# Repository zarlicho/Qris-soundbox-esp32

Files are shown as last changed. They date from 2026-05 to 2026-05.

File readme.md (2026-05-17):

# QRIS Soundbox System - Complete Documentation

## Project Overview

QRIS Soundbox adalah sistem notifikasi pembayaran realtime yang dikembangkan untuk menerima dan memproses notifikasi pembayaran QRIS melalui protokol MQTT. Sistem ini mengintegrasikan payment gateway Midtrans dengan device soundbox melalui Adafruit server yang berfungsi sebagai webhook endpoint dan MQTT broker.

## PCB design
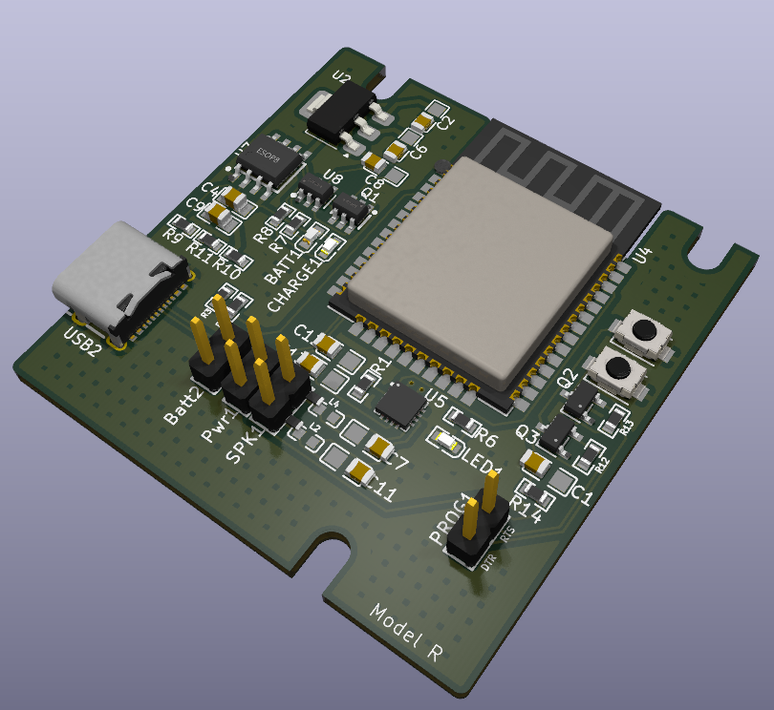
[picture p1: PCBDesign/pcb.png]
PCB


## System Architecture

### Core Components

1. **Payment Gateway**: Midtrans sebagai processor pembayaran QRIS
2. **Server Infrastructure**: Adafruit server dengan webhook endpoint dan MQTT broker
3. **QRIS Soundbox Device**: Device subscriber yang memberikan feedback audio dan visual
4. **Monitoring Dashboard**: Adafruit IO untuk monitoring dan logging

### Technology Stack

- **Payment Processing**: Midtrans Payment Gateway
- **Communication Protocol**: MQTT (Message Queuing Telemetry Transport)
- **Server Platform**: Adafruit IO
- **Device Communication**: MQTT Subscribe/Publish pattern
- **Data Format**: JSON for payment callback data

## System Flow Documentation

### 1. Payment Initiation Flow

**Customer Journey:**
- Customer melakukan scan QR code menggunakan mobile banking atau e-wallet
- Aplikasi mobile memproses pembayaran melalui sistem perbankan
- Data pembayaran diteruskan ke Midtrans payment gateway untuk processing

### 2. Payment Processing Flow

**Midtrans Processing:**
- Midtrans memvalidasi dan memproses transaksi pembayaran
- System menentukan status pembayaran (Success/Failed)
- Callback notification digenerate berdasarkan hasil processing

### 3. Webhook Callback Flow

**Server Side Processing:**
- Midtrans mengirim HTTP POST callback ke webhook endpoint Adafruit server
- Server menerima dan memvalidasi data callback
- Data callback diparse dan diverifikasi integritasnya
- Jika valid, data diproses untuk publikasi ke MQTT broker

**Data Validation Steps:**
- Signature verification untuk keamanan
- Transaction ID validation
- Amount dan merchant validation
- Timestamp verification

### 4. MQTT Publication Flow

**Message Broadcasting:**
- Validated payment data dipublikasi ke MQTT broker (Adafruit IO)
- Data dikirim ke specific topic: `qris/payment/notification`
- Message format menggunakan JSON structure
- QoS (Quality of Service) level ditentukan untuk reliability

**Sample MQTT Payload:**
```json
{
    "additionalInfo": {
        "issuerID": "93600821",
        "nettAmount": "9990.00",
        "payerName": "TEST",
        "payerPhoneNumber": "9360082112345678919",
        "paymentReferenceNo": "J0CP1INR2LOO",
        "posID": "A01",
        "retrievalReferenceNo": "1cqn60h00775",
        "totalRefund": "0.00"
    },
    "amount": {
        "currency": "IDR",
        "value": "10000.00"
    },
    "latestTransactionStatus": "00",
    "originalPartnerReferenceNo": "23545346"
}
```

### 5. Device Subscription Flow

**QRIS Soundbox Processing:**
- Device maintain persistent connection ke MQTT broker
- Subscribe ke topic `qris/payment/notification`
- Receive realtime notification ketika ada payment baru
- Parse JSON payload untuk extract payment information

### 6. User Feedback Flow

**Audio & Visual Feedback:**
- **Success Payment**: Play success sound + display transaction details
- **Failed Payment**: Play error sound + display failure message
- **Display Information**: Amount, transaction time, status, transaction ID
- **Logging**: Record transaction untuk audit trail

### 7. Monitoring & Analytics Flow

**Dashboard Integration:**
- Adafruit IO dashboard menampilkan realtime payment statistics
- Mobile app atau web interface untuk remote monitoring
- Transaction history dan analytics
- Device status monitoring (online/offline)

## Technical Implementation Details

### MQTT Configuration

**Broker Settings:**
- **Host**: io.adafruit.com
- **Port**: 1883 (non-SSL) atau 8883 (SSL)
- **Username**: Adafruit IO username
- **Key**: Adafruit IO key
- **Keep Alive**: 60 seconds
- **Clean Session**: True

### Webhook Endpoint Configuration

**Midtrans Webhook Setup:**
- **URL**: `https://io.adafruit.com/api/v2/webhooks/[webhook-key]`
- **Method**: POST
- **Content-Type**: application/json
- **Timeout**: 30 seconds
- **Retry**: 3 attempts dengan exponential backoff

### Error Handling Strategy

**Connection Resilience:**
- Auto-reconnect untuk MQTT connection
- Offline message queuing
- Retry mechanism untuk failed callbacks
- Graceful degradation ketika server unavailable

**Data Integrity:**
- Duplicate transaction detection
- Checksum verification
- Transaction sequence validation
- Timeout handling untuk stuck transactions

### Security Considerations

**Data Protection:**
- HTTPS untuk webhook communications
- MQTT over SSL/TLS
- Signature validation dari Midtrans
- API key rotation policy
- Access control untuk MQTT topics

**Privacy Compliance:**
- Customer data anonymization
- PCI DSS compliance untuk payment data
- Log data retention policy
- Secure storage untuk transaction records

## Deployment Architecture

### Production Environment

**Infrastructure Requirements:**
- Reliable internet connection untuk device
- Backup power supply untuk continuous operation
- Local storage untuk offline transaction queuing
- Audio output system untuk sound notifications

**Scalability Considerations:**
- Multiple device support dengan unique client IDs
- Load balancing untuk high-volume transactions
- Database optimization untuk transaction storage
- Caching strategy untuk frequent queries

---

## System Flow Diagram

```mermaid
flowchart TD
    A[Customer] --> B[Scan QR Code]
    B --> C[Mobile Banking/E-Wallet App]
    C --> D[Payment Processing]
    D --> E[Midtrans Payment Gateway]
    
    E --> F{Payment Status}
    F -->|Success| G[Payment Callback]
    F -->|Failed| H[Failed Callback]
    
    G --> I[Webhook Endpoint<br/>Adafruit Server]
    H --> I
    
    I --> J[Process Callback Data]
    J --> K[Validate Payment Data]
    K --> L{Data Valid?}
    
    L -->|Yes| M[Publish to MQTT Broker<br/>Adafruit IO]
    L -->|No| N[Log Error & Reject]
    
    M --> O[MQTT Topic<br/>qris/payment/notification]
    
    O --> P[QRIS Soundbox Device<br/>MQTT Subscriber]
    P --> Q[Receive Payment Data]
    Q --> R[Parse JSON Data]
    R --> S[Extract Payment Info<br/>Amount, Status, Transaction ID]
    
    S --> T{Payment Success?}
    T -->|Yes| U[Play Success Sound]
    T -->|Failed| V[Play Failed Sound]
    
    U --> W[Display Transaction Info<br/>Amount, Time, Status]
    V --> W
    
    W --> X[Log Transaction]
    X --> Y[Ready for Next Payment]
    
    %% Additional Components
    Z[Adafruit IO Dashboard] --> O
    AA[Mobile App/Web Monitor] --> Z
    
    %% Styling
    classDef customer fill:#e1f5fe
    classDef payment fill:#f3e5f5
    classDef server fill:#e8f5e8
    classDef device fill:#fff3e0
    classDef data fill:#fce4ec
    
    class A,B,C customer
    class D,E,F,G,H payment
    class I,J,K,L,M,O,Z server
    class P,Q,R,S,T,U,V,W,X,Y device
    class AA data
```

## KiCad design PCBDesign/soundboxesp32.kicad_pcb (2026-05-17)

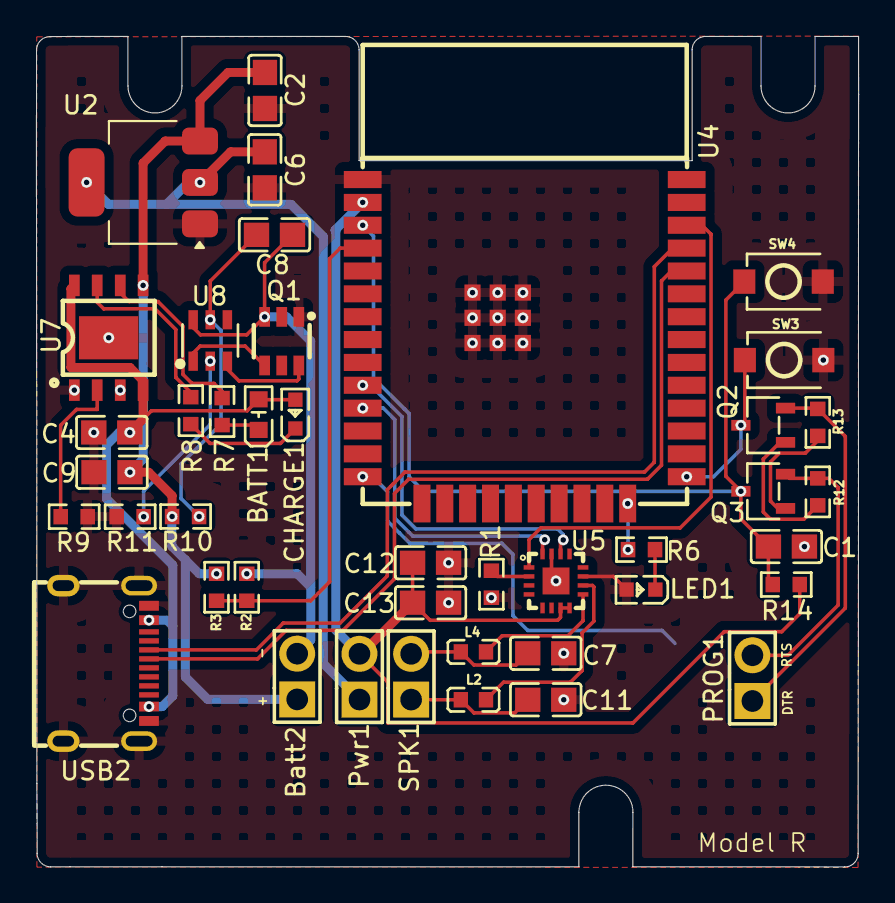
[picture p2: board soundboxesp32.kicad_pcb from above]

Board: 2 copper layers, 45.7 x 46.1 mm, 43 parts (1 on the bottom side), 35 nets.

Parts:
BATT1: A-SP192DGHC-C01-4T; LED0603-FD
Batt2: ZX-PZ2.54-1-2PZZ; HDR-TH_2P-P2.54-V-M
C1, C4, C8, C12: 100nF; C0805
C2, C6: 22uF; C0805
C7, C11: 220pF; C0805
C9, C13: 10uF; C0805
CHARGE1: XL-1608SURC-06; LED0603-RD_RED
L2, L4: 330Ω; L0603
LED1: XL-1608SURC-06; LED0603-RD_RED
PROG1: ZX-PZ2.54-1-2PZZ; HDR-TH_2P-P2.54-V-M
Pwr1: ZX-PZ2.54-1-2PZZ; HDR-TH_2P-P2.54-V-M
Q1: FS8205; SOT-23-6_L2.9-W1.6-P0.95-LS2.8-BR
Q2, Q3: MMBT3904LT1G; SOT-23-3_L2.9-W1.6-P1.90-LS2.8-BR
R1, R3: RC0603FR-07100KL; R0603
R2: FRC0603F3003TS; R0603
R6, R7, R8, R9, R11: 1K; R0603
R10: 100Ω; R0603
R12, R13, R14: 10K; R0603
SPK1: ZX-PZ2.54-1-2PZZ; HDR-TH_2P-P2.54-V-M
SW1, SW3, SW4: TS-1088-AR02016; SW-SMD_L3.9-W3.0-P4.45
U2: AMS1117-3.3; SOT-223-3_TabPin2
U4: ESP32-WROOM-32E(4MB); WIFI-SMD_ESP32-WROOM-32E
U5: MAX98357AETE+T; TQFN-16_L3.0-W3.0-P0.50-BL-EP1.5
U7: TP4056; ESOP-8_L4.9-W3.9-P1.27-LS6.0-BL-EP
U8: DW01A_C2927799; SOT-23-6_L2.9-W1.6-P0.95-LS2.8-BL
USB2: TYPE-C 16PIN 2MD(073); USB-C-SMD_TYPE-C-6PIN-2MD-073

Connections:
+3.3V: C12.1, C13.1, Pwr1.2, R14.2, U4.2 (3V3), U5.7 (VDD), U5.8 (VDD)
+5V: BATT1.1 (A), C4.1, CHARGE1.2 (A), U7.4 (VCC), U7.8 (CE), USB2.2 (VBUS), USB2.11 (VBUS)
+BATT: Batt2.1, C2.2, C9.1, R3.2, R10.2, U2.3 (VI), U7.5 (BAT)
BCLK: U4.11 (IO26), U5.16 (BCLK)
DIN: U4.36 (IO22), U5.1 (DIN)
DTR: PROG1.1, Q2.2, R13.1
GND: C1.2, C2.1, C4.2, C6.1, C7.1, C9.2, C11.1, C12.2, C13.2, LED1.2 (A), Q1.1 (S1), R1.1, R9.2, R11.1, SW1.2, SW3.2, SW4.2, U2.1 (GND), U4.1 (GND), U4.39 (GND), U5.11 (GND), U5.15 (GND), U5.17 (EP), U7.1 (TEMP), U7.3 (GND), U7.9 (EP), USB2.1 (GND), USB2.12 (GND), USB2.13 (SHELL), USB2.14 (SHELL)
GPIO0: Q2.3, SW3.1, U4.25 (IO0)
IO12: SW1.1, U4.14 (IO12)
LRC: U4.10 (IO25), U5.14 (LRCLK)
unnamed: BATT1.2 (K), R7.2
unnamed: C7.2, L4.2, SPK1.2
unnamed: C11.2, L2.2, SPK1.1
unnamed: CHARGE1.1 (K), R8.2
unnamed: LED1.1 (K), R6.2
unnamed: Q1.6 (G1), U8.3 (OC)
unnamed: Q1.4 (G2), U8.1 (OD)
unnamed: Batt2.2, C8.2, Q1.3 (S2), R2.1, U8.6 (VSS)
unnamed: Q2.1, R12.2
unnamed: Q3.1, R13.2
unnamed: C6.2, Pwr1.1, U2.2 (VO)
unnamed: R6.1, U4.24 (IO2)
unnamed: R1.2, U5.2 (GAIN_SLOT)
unnamed: L2.1, U5.10 (OUTN)
unnamed: L4.1, U5.9 (OUTP)
unnamed: R9.1, U7.2 (PROG)
unnamed: R8.1, U7.7 (~CHRG)
unnamed: R7.1, U7.6 (~STDBY)
unnamed: R11.2, U8.2 (CSI)
unnamed: C8.1, R10.1, U8.5 (VDD)
RESET: C1.1, Q3.3, R14.1, SW4.1, U4.3 (EN)
RTS: PROG1.2, Q3.2, R12.1
RX: U4.34 (RXD0), USB2.6 (DP1), USB2.8 (DP2)
SENSOR_VP: R2.2, R3.1, U4.4 (SENSOR_VP)
TX: U4.35 (TXD0), USB2.5 (DN2), USB2.7 (DN1)

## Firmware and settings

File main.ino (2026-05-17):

#include "Adafruit_MQTT_Client.h"
#include <HTTPClient.h>
#include <WiFiClientSecure.h>
#include <WiFi.h>
#include <WiFiManager.h>
#include "Adafruit_MQTT.h"
#include "ArduinoJson.h"
#include "Arduino.h"
#include <Arduino.h>
#include <LittleFS.h>
#include "driver/i2s.h"

// dac connection
#define I2S_DOUT  22
#define I2S_BCLK  26
#define I2S_LRC   25

// ============Adafruit MQTT CONFIG============
#define AIO_SERVER "io.adafruit.com"
#define AIO_SERVERPORT 1883
#define AIO_USERNAME "your adafruit_username"
#define AIO_KEY "your adafruit_key"
#define FeedName "your feed_name" // kalau pakai adafruit mqtt, biasanya formatnya username/feeds/feedname

// ---------- WAV parsing ----------
struct WavFmt {
  uint16_t audioFormat;   // 1 = PCM
  uint16_t numChannels;   // 1 = mono, 2 = stereo
  uint32_t sampleRate;    // e.g. 16000
  uint16_t bitsPerSample; // 16
  uint32_t dataOffset;    // posisi awal data PCM
  uint32_t dataSize;      // ukuran data PCM (byte)
};

// PIN CONFIG
int button = 12;
int button2 = 13;
float volume = 5.0f;
long buttonTimer = 0;
long longPressTime = 5000;
bool volActive = false;
boolean buttonActive = false;
boolean longPressActive = false;

// MQTT CONTROL
unsigned long lastMQTTCheck = 0;
unsigned long lastMQTTConnectAttempt = 0;
const unsigned long mqttInterval = 100;
const unsigned long mqttReconnectInterval = 30000; // 30 sec
bool mqttConnected = false;

// ---- WiFi reconnect control ----
unsigned long lastWiFiReconnectAttempt = 0;
const unsigned long wifiReconnectInterval = 10000; // 10s
bool portalRequested = false;

bool hasSavedWiFi() {
  // Deteksi kredensial tersimpan di NVS
  // WiFi.SSID() biasanya berisi SSID terakhir yang tersimpan
  return WiFi.psk().length() > 0;
}

void tryWiFiReconnect() {
  if (WiFi.status() != WL_CONNECTED) {
    Serial.println("[WiFi] Lost. Reconnecting...");
    // panggil reconnect cepat
    WiFi.reconnect();
  }
}

// OBJECTS
WiFiClient client;
WiFiClientSecure clientSecure;
HTTPClient http;
WiFiManager wifiManager;

// mqtt config for adafruit only
Adafruit_MQTT_Client mqtt(&client, AIO_SERVER, AIO_SERVERPORT, AIO_USERNAME, AIO_KEY);
Adafruit_MQTT_Subscribe sndBox = Adafruit_MQTT_Subscribe(&mqtt, AIO_USERNAME "/feeds/" FeedName);

StaticJsonDocument<1264> doc;

// AIRTABLE CONFIG
const char* airtableToken = "your_airtable_token";  // Personal Access Token
const char* baseId = "your_airtable_base_id";       // Base ID
const char* tableName = "your_airtable_table_name";
String airtableURL = "https://api.airtable.com/v0/" + String(baseId) + "/" + tableName;

// Custom CSS for dark mode and styling
const char* customCSS = R"rawliteral(
<style>
  :root {
    --bg-primary: #1a1a1a;
    --bg-secondary: #2d2d2d;
    --text-primary: #ffffff;
    --text-secondary: #b0b0b0;
    --accent-color: #00d4aa;
    --accent-hover: #00b894;
    --border-color: #404040;
    --input-bg: #333333;
    --danger-color: #ff6b6b;
  }
  
  * {
    box-sizing: border-box;
    margin: 0;
    padding: 0;
  }
  
  body {
    font-family: 'Segoe UI', Tahoma, Geneva, Verdana, sans-serif;
    background: linear-gradient(135deg, var(--bg-primary) 0%, var(--bg-secondary) 100%);
    color: var(--text-primary);
    min-height: 100vh;
    padding: 20px;
    line-height: 1.6;
  }
  
  .container {
    max-width: 500px;
    margin: 0 auto;
    background: var(--bg-secondary);
    border-radius: 15px;
    box-shadow: 0 10px 30px rgba(0, 0, 0, 0.5);
    overflow: hidden;
  }
  
  .header {
    background: linear-gradient(135deg, var(--accent-color), var(--accent-hover));
    padding: 30px 20px;
    text-align: center;
    color: white;
  }
  
  .header h1 {
    font-size: 2.2em;
    margin-bottom: 10px;
    font-weight: 300;
  }
  
  .header p {
    opacity: 0.9;
    font-size: 1.1em;
  }
  
  .content {
    padding: 30px;
  }
  
  h2, h3 {
    color: var(--accent-color);
    margin-bottom: 20px;
    font-weight: 400;
  }
  
  .btn {
    display: inline-block;
    background: var(--accent-color);
    color: white;
    padding: 12px 30px;
    text-decoration: none;
    border-radius: 25px;
    border: none;
    cursor: pointer;
    font-size: 1em;
    transition: all 0.3s ease;
    margin: 10px 5px;
    min-width: 120px;
  }
  
  .btn:hover {
    background: var(--accent-hover);
    transform: translateY(-2px);
    box-shadow: 0 5px 15px rgba(0, 212, 170, 0.3);
  }
  
  .btn-secondary {
    background: transparent;
    border: 2px solid var(--accent-color);
    color: var(--accent-color);
  }
  
  .btn-secondary:hover {
    background: var(--accent-color);
    color: white;
  }
  
  input[type="text"], input[type="password"], select {
    width: 100%;
    padding: 15px;
    background: var(--input-bg);
    border: 2px solid var(--border-color);
    border-radius: 8px;
    color: var(--text-primary);
    font-size: 1em;
    margin: 10px 0;
    transition: border-color 0.3s ease;
  }
  
  input[type="text"]:focus, input[type="password"]:focus, select:focus {
    outline: none;
    border-color: var(--accent-color);
    box-shadow: 0 0 10px rgba(0, 212, 170, 0.2);
  }
  
  .status-indicator {
    display: inline-block;
    width: 12px;
    height: 12px;
    border-radius: 50%;
    margin-right: 10px;
    background: var(--danger-color);
    animation: pulse 2s infinite;
  }
  
  .status-indicator.connected {
    background: var(--accent-color);
  }
  
  @keyframes pulse {
    0% { opacity: 1; }
    50% { opacity: 0.5; }
    100% { opacity: 1; }
  }
  
  .info-card {
    background: var(--bg-primary);
    padding: 20px;
    border-radius: 10px;
    margin: 20px 0;
    border-left: 4px solid var(--accent-color);
  }
  
  .network-list {
    max-height: 300px;
    overflow-y: auto;
  }
  
  .network-item {
    padding: 15px;
    border-bottom: 1px solid var(--border-color);
    cursor: pointer;
    transition: background 0.3s ease;
  }
  
  .network-item:hover {
    background: var(--bg-primary);
  }
  
  .signal-strength {
    float: right;
    color: var(--text-secondary);
  }
  
  .footer {
    text-align: center;
    padding: 20px;
    color: var(--text-secondary);
    border-top: 1px solid var(--border-color);
  }
  
  @media (max-width: 600px) {
    body { padding: 10px; }
    .container { margin: 0; }
    .header h1 { font-size: 1.8em; }
    .content { padding: 20px; }
  }
</style>
)rawliteral";

// Landing page HTML
const char* landingPageHTML = R"rawliteral(
<!DOCTYPE html>
<html>
<head>
  <meta charset="UTF-8">
  <meta name="viewport" content="width=device-width, initial-scale=1.0">
  <title>Config</title>
</head>
<body>
  <div class="container">
    <div class="header">
      <h1>Soundbox Settings</h1>
    </div>
    
    <div class="content">
      <div class="info-card">
        <h3><span class="status-indicator"></span>Device Status</h3>
        <p><strong>Device ID:</strong> BYR-AJA001</p>
        <p><strong>Status:</strong> Ready for Configuration</p>
      </div>
      
      <div style="text-align: center; margin: 30px 0;">
        <p style="color: var(--text-secondary); margin-bottom: 30px;">
          Settings Wifi untuk device Qris soundbox
        </p>
        
        <a href="/wifi" class="btn">🔧 Konfigurasi WiFi</a>
        
      </div>
      
      <div class="info-card">
        <h3>Langkah-langkah</h3>
        <ol style="color: var(--text-secondary); padding-left: 20px;">
          <li>Klik "Konfigurasi WiFi"</li>
          <li>Pilih Wifi yang tersedia di list</li>
          <li>Masukan password</li>
          <li>Klik save dan tunggu hingga terhubung</li>
        </ol>
      </div>
    </div>
    
    <div class="footer">
      <p>Qris Soundbox BayarAja</p>
    </div>
  </div>
</body>
</html>
)rawliteral";

bool parseWavHeader(File &f, WavFmt &fmt) {
  f.seek(0);
  uint8_t hdr[12];
  if (f.read(hdr, 12) != 12) return false;
  if (memcmp(hdr, "RIFF", 4) != 0 || memcmp(hdr + 8, "WAVE", 4) != 0) return false;

  bool gotFmt = false, gotData = false;
  uint32_t pos = 12;
  while (pos + 8 <= f.size()) {
    f.seek(pos);
    char chunkId[5] = {0};
    f.read((uint8_t*)chunkId, 4);
    uint32_t chunkSize;
    f.read((uint8_t*)&chunkSize, 4);

    pos += 8;
    if (!memcmp(chunkId, "fmt ", 4)) {
      if (chunkSize < 16) return false;
      uint16_t audioFormat, numChannels, bitsPerSample, blockAlign;
      uint32_t sampleRate, byteRate;
      f.read((uint8_t*)&audioFormat, 2);
      f.read((uint8_t*)&numChannels, 2);
      f.read((uint8_t*)&sampleRate, 4);
      f.read((uint8_t*)&byteRate, 4);
      f.read((uint8_t*)&blockAlign, 2);
      f.read((uint8_t*)&bitsPerSample, 2);
      // skip extra fmt bytes if any
      if (chunkSize > 16) f.seek(pos + chunkSize);

      fmt.audioFormat   = audioFormat;
      fmt.numChannels   = numChannels;
      fmt.sampleRate    = sampleRate;
      fmt.bitsPerSample = bitsPerSample;
      gotFmt = true;
      pos += chunkSize;
    } else if (!memcmp(chunkId, "data", 4)) {
      fmt.dataOffset = pos;
      fmt.dataSize   = chunkSize;
      gotData = true;
      break; // data chunk terakhir yang kita butuhkan
    } else {
      // lewati chunk lain (LIST, fact, dsb.)
      pos += chunkSize;
    }
    // align ke genap
    if (chunkSize & 1) pos++;
  }
  return gotFmt && gotData && fmt.audioFormat == 1 && fmt.bitsPerSample == 16;
}

// ---------- Volume ----------
inline void apply_volume(uint8_t* buffer, size_t bytesRead, float vol) {
  int16_t* s = (int16_t*)buffer;
  size_t n = bytesRead / 2;
  for (size_t i = 0; i < n; i++) {
    int32_t v = (int32_t)(s[i] * vol);
    if (v > 32767) v = 32767;
    if (v < -32768) v = -32768;
    s[i] = (int16_t)v;
  }
}

// edited i2s_init
void i2s_init(uint32_t sample_rate, int channels) {
  i2s_config_t i2s_config = {
    .mode = (i2s_mode_t)(I2S_MODE_MASTER | I2S_MODE_TX),
    .sample_rate = (int)sample_rate,                    // pakai dari WAV
    .bits_per_sample = I2S_BITS_PER_SAMPLE_16BIT,
    .channel_format = channels == 2
        ? I2S_CHANNEL_FMT_RIGHT_LEFT
        : I2S_CHANNEL_FMT_ONLY_RIGHT,                   // atau ONLY_LEFT
    .communication_format = I2S_COMM_FORMAT_STAND_I2S,  // cukup STAND_I2S
    .intr_alloc_flags = ESP_INTR_FLAG_LEVEL1,
    .dma_buf_count = 8,
    .dma_buf_len   = 256,                               // dulu 64
    .use_apll = true,                                   // clock lebih stabil
    .tx_desc_auto_clear = true,
    .fixed_mclk = 0
  };
  // i2s_pin_config_t pin_config = { I2S_BCLK, I2S_LRC, I2S_DOUT, I2S_PIN_NO_CHANGE };
  i2s_pin_config_t pin_config = {
    .bck_io_num = I2S_BCLK,
    .ws_io_num  = I2S_LRC,
    .data_out_num = I2S_DOUT,
    .data_in_num  = I2S_PIN_NO_CHANGE
  };


  i2s_driver_install(I2S_NUM_0, &i2s_config, 0, NULL);
  i2s_set_pin(I2S_NUM_0, &pin_config);
  i2s_set_clk(I2S_NUM_0, sample_rate, I2S_BITS_PER_SAMPLE_16BIT,
              (channels == 2) ? I2S_CHANNEL_STEREO : I2S_CHANNEL_MONO);
}

void setupCustomWiFiManager() {
  // Set custom menu items including home/landing page
  std::vector<const char *> menu = {"wifi", "info", "sep", "restart", "exit"};
  wifiManager.setMenu(menu);

  // Set custom CSS for dark mode
  wifiManager.setCustomHeadElement(customCSS);

  // Add custom landing page as root
  wifiManager.setWebServerCallback([&]() {
    wifiManager.server->on("/", [&]() {
      wifiManager.server->send(200, "text/html", String(customCSS) + landingPageHTML);
    });
    
    // Custom info page
    wifiManager.server->on("/info", [&]() {
      String infoHTML = String(customCSS) + R"rawliteral(
        <!DOCTYPE html>
        <html>
        <head>
          <meta charset="UTF-8">
          <meta name="viewport" content="width=device-width, initial-scale=1.0">
          <title>Device Information</title>
        </head>
        <body>
          <div class="container">
            <div class="header">
              <h1>📊 Device Information</h1>
              <p>System Status and Details</p>
            </div>
            
            <div class="content">
              <div class="info-card">
                <h3>💾 System Information</h3>
                <p><strong>Device ID:</strong> BYR-AJA001</p>
                <p><strong>Merchant ID:</strong> )rawliteral" + subMerchantId + R"rawliteral(</p>
                <p><strong>Volume Level:</strong> )rawliteral" + String(volume) + R"rawliteral(/30</p>
              </div>
              
              <div style="text-align: center; margin: 30px 0;">
                <a href="/" class="btn">🏠 Home</a>
                <a href="/wifi" class="btn">🔧 WiFi Config</a>
              </div>
            </div>
            
            <div class="footer">
              <p>Qris Soundbox BayarAja | Real-time Data</p>
            </div>
          </div>
        </body>
        </html>
      )rawliteral";
      
      wifiManager.server->send(200, "text/html", infoHTML);
    });
  });

  // Configure WiFiManager settings
  wifiManager.setConfigPortalTimeout(300); // 5 minutes timeout
  wifiManager.setConnectTimeout(20);       // 20 seconds to connect
  wifiManager.setAPCallback([](WiFiManager *myWiFiManager) {
    Serial.println("Config portal started");
    Serial.print("Connect to: ");
    Serial.println(myWiFiManager->getConfigPortalSSID());
    Serial.print("Go to: http://");
    Serial.println(WiFi.softAPIP());
  });

  // Set custom AP name and password (optional)
  wifiManager.setAPStaticIPConfig(IPAddress(192, 168, 1, 1), 
                         IPAddress(192, 168, 1, 1), 
                         IPAddress(255, 255, 255, 0));
}

// ================= SETUP =================
void setup() {
  Serial.begin(115200);

  pinMode(button, INPUT_PULLUP);
  pinMode(button2, INPUT_PULLUP);

  if (!LittleFS.begin()) {
    Serial.println("LittleFS mount failed");
    return;
  }

  // WiFi basic init
  WiFi.mode(WIFI_STA);
  WiFi.persistent(true);
  WiFi.setAutoReconnect(true);

  // WiFiManager setup & styling
  setupCustomWiFiManager();
  wifiManager.setWiFiAutoReconnect(true);

  // KUNCI: matikan fallback portal otomatis.
  wifiManager.setEnableConfigPortal(false);
  // Waktu connect pendek saja; selebihnya kita handle sendiri.
  wifiManager.setConnectTimeout(15);

  play(19);

  bool connected = false;

  if (hasSavedWiFi()) {
    Serial.println("[WiFi] Saved credentials detected. Fast connect...");
    // Coba pakai kredensial tersimpan TANPA membuka portal.
    connected = wifiManager.autoConnect(); // dengan enableConfigPortal(false) ini tidak akan buka portal
    if (!connected) {
      Serial.println("[WiFi] Fast connect failed, will retry in loop (no portal).");
    }
  } else {
    Serial.println("[WiFi] No saved credentials. Starting config portal...");
    // First-time provisioning: buka portal sekali ini.
    // (Kalau mau SSID/Password portal custom, pakai param di sini)
    connected = wifiManager.startConfigPortal("BYRaja-dvc-01", "12345678");
  }

  if (!connected && !hasSavedWiFi()) {
    // Kalau user kabur dari portal tanpa save, aman: kita reboot saja
    Serial.println("[WiFi] No creds saved. Restarting...");
    delay(1000);
    ESP.restart();
  }

  if (WiFi.status() == WL_CONNECTED) {
    Serial.println("WiFi connected successfully!");
    Serial.print("IP address: "); Serial.println(WiFi.localIP());
    Serial.print("MAC address: "); Serial.println(WiFi.macAddress());
  } else {
    Serial.println("[WiFi] Not connected yet. Will keep retrying silently.");
  }

  // MQTT init
  mqtt.subscribe(&sndBox);
  clientSecure.setInsecure();
  http.addHeader("Content-Type", "application/json");

  MQTT_connect();
}

// ================= LOOP =================
void loop() {
  ResetSettings(); // long-press bisa minta portal on-demand

  unsigned long now = millis();

  // Reconnect WiFi diam-diam tiap 10 detik kalau putus
  if (now - lastWiFiReconnectAttempt >= wifiReconnectInterval) {
    lastWiFiReconnectAttempt = now;
    if (WiFi.status() != WL_CONNECTED) {
      tryWiFiReconnect();
    }
  }

  // MQTT reconnect logic (punyamu)
  if (!mqttConnected && (now - lastMQTTConnectAttempt >= mqttReconnectInterval)) {
    Serial.println("Attempting MQTT reconnection...");
    MQTT_connect();
    lastMQTTConnectAttempt = now;
  }

  if (mqttConnected && (now - lastMQTTCheck >= mqttInterval)) {
    lastMQTTCheck = now;

    if (!mqtt.connected()) {
      Serial.println("MQTT connection lost!");
      mqttConnected = false;
      lastMQTTConnectAttempt = now;
      return;
    }

    Adafruit_MQTT_Subscribe *subscription = mqtt.readSubscription(0);
    if (subscription && subscription == &sndBox) {
      const char *document = (const char *)sndBox.lastread;
      GetPay(document);
    }
  }
}

// ================= OTHER FUNCTIONS =================
void GetPay(const char *document) {
  size_t documentLength = strlen(document);
  if (documentLength > 0) {
    DeserializationError error = deserializeJson(doc, document);
    if (!error) {
      // ============FOR midtrans============
      if (doc["transaction_status"] == "settlement"){
        long amount = doc["gross_amount"];
        String created = doc["transaction_time"];
        const char *status = doc["transaction_status"];
        const char *source = doc["payment_type"];
        const char *nameHolder = doc["transaction_id"];
        
        Serial.print("PAYMENT SUCCESS WITH ");
        Serial.println(source);
        Serial.println();
        Serial.print(F("amount: "));
        Serial.println(amount);
        Serial.print(F("status: "));
        Serial.println(status);
        Serial.println(created);
        num2sound((int)amount);
        sendDataToAirtable(created, nameHolder, status, source, amount);
      }
    }
  }
}

void MQTT_connect() {
  int8_t ret;
  if (mqtt.connected()) {
    mqttConnected = true;
    return;
  }
  Serial.print("Connecting to MQTT... ");
  uint8_t retries = 3;
  while ((ret = mqtt.connect()) != 0 && retries > 0) {
    Serial.println(mqtt.connectErrorString(ret));
    mqtt.disconnect();
    delay(2000);
    retries--;
  }
  if (ret == 0) {
    Serial.println("MQTT Connected!");
    mqttConnected = true;
    play(23);
  } else {
    Serial.println("MQTT connection failed.");
    mqttConnected = false;
  }
}

void play(int fileNumber) {
  String path = String("/")+ String(fileNumber) + ".wav";
  File file = LittleFS.open(path, "r");
  if (!file) { Serial.printf("Open fail: %s\n", path); return; }

  WavFmt fmt;
  if (!parseWavHeader(file, fmt)) {
    Serial.println("WAV parse error (harus PCM 16-bit).");
    file.close();
    return;
  }

  // init I2S sesuai file
  i2s_driver_uninstall(I2S_NUM_0); // bersihkan jika ada
  i2s_init(fmt.sampleRate, fmt.numChannels);

  // lompat ke awal data PCM sebenarnya
  file.seek(fmt.dataOffset);

  // buffer lebih besar → stabil
  static uint8_t buffer[2048];
  Serial.printf("Play %s @ %lu Hz, %u ch, 16-bit, data=%lu bytes, vol=%.2f\n",
                path, (unsigned long)fmt.sampleRate, fmt.numChannels,
                (unsigned long)fmt.dataSize, volume);

  uint32_t remaining = fmt.dataSize;
  while (remaining > 0) {
    size_t toRead = remaining > sizeof(buffer) ? sizeof(buffer) : remaining;
    size_t bytesRead = file.read(buffer, toRead);
    if (bytesRead == 0) break;

    apply_volume(buffer, bytesRead, volume);

    size_t bytesWritten = 0;
    i2s_write(I2S_NUM_0, buffer, bytesRead, &bytesWritten, portMAX_DELAY);
    remaining -= bytesRead;
  }

  file.close();
  Serial.println("Done.");
}

/*
void play(int fileNumber) {
  String myAudio = String("/01/")+ String(fileNumber) + ".wav";
  File file = SD.open(myAudio);
  if (!file) {
    Serial.println("Failed to open file");
    return; // Changed from while(1) to return to prevent infinite loop
  }

  skip_wav_header(file);

  uint8_t buffer[1024];
  Serial.println("Playing WAV...");
  while (file.available()) {
    size_t bytesRead = file.read(buffer, sizeof(buffer));
    size_t bytesWritten;
    i2s_write(I2S_NUM_0, buffer, bytesRead, &bytesWritten, portMAX_DELAY);
  }

  file.close();
  Serial.println("Playback done.");
}
*/

void num2sound(int bill) {
  play(20);
  String blng = Terbilang(bill) + " 22";
  for (int i = 0; i < blng.length(); i++) {
    String word = "";
    while (i < blng.length() && blng[i] != ' ') {
      word += blng[i];
      i++;
    }
    if (word != "") {
      play(word.toInt());
      Serial.print("FileName: ");
      Serial.println(word.toInt());
      if (i == blng.length());
    }
  }
}

String Terbilang(int n) {
  String hasil = "";
  if (n == 0) return hasil;
  if (n >= 0 && n <= 11) hasil = String(n);
  else if (n < 20) hasil = Terbilang(n % 10) + " 0012 ";
  else if (n < 100) hasil = Terbilang(n / 10) + " 0014 " + Terbilang(n % 10);
  else if (n < 200) hasil = " 0017 " + Terbilang(n - 100);
  else if (n < 1000) hasil = Terbilang(n / 100) + " 0015 " + Terbilang(n % 100);
  else if (n < 2000) hasil = " 0018 " + Terbilang(n - 1000);
  else if (n < 1000000) hasil = Terbilang(n / 1000) + " 0016 " + Terbilang(n % 1000);
  else if (n < 1000000000) hasil = Terbilang(n / 1000000) + " 0013 " + Terbilang(n % 1000000);
  return hasil;
}
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
